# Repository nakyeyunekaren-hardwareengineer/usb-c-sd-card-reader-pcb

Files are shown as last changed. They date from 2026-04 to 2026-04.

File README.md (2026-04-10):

# usb-c-sd-card-reader-pcb
Custom USB-C microSD card reader hardware project featuring schematic design, PCB design and system validation.

# USB-C microSD Card Reader

A custom USB-C microSD card reader PCB designed around the **Genesys Logic GL823K** controller. This project covers the full hardware development flow, from component selection and 
schematic capture to PCB layout, PCB fabrication and assembly ordering, hardware bring-up, hardware debugging and successful memory card read validation.

## Overview

The goal of this project was to design and build a compact USB-C memory card reader that interfaces with a microSD card and communicates with a host device over USB.

This project was completed as a practical electronics and PCB design exercise, with a strong focus on:
- component selection
- schematic design
- PCB layout
- design for manufacture and assembly
- PCB fabrication and assembly ordering
- hardware bring-up
- power rail verification
- debugging and validation

## Key Design Approach

Before starting the design, I selected components carefully to make assembly easier and faster through **JLCPCB**. 
I made sure the parts I chose were available in **JLCPCB Basic** or **Extended** libraries so that the board could be manufactured and assembled with minimal friction.

It was important in designing not just for functionality, but also for **manufacturability** and **assembly convenience**.

## Main Components

The design used the following key parts:

- **GL823K-HCY04** — USB 2.0 flash card reader controller
- **TYPE-C 16PIN 2MD(073)** — USB-C connector
- **Molex 503398-1892** — microSD card connector
- **PRTR5V0U2X / PRTR5V0U2X,215** — USB ESD protection device
- supporting capacitors, resistors and power components for decoupling, pull-downs and signal support

## 3D image


## Printed board


## Features

- USB-C interface
- microSD card support
- GL823K-based controller
- Custom PCB design
- ESD protection
- Manufactured and assembled through JLCPCB
- Working prototype validated through hardware testing

## Tools Used

- **Altium Designer** for schematic capture and PCB layout
- **JLCPCB** for PCB fabrication and PCB assembly
- lab test equipment for bring-up and debugging
- USB host (Laptop) for functional testing

## Manufacturing and Assembly

Fabrication and assembly was done by JLPCB:
- **PCB fabrication**
- **PCB assembly (PCBA)**

This included selecting assembly-friendly parts, preparing manufacturing outputs, and understanding how to structure a design so it can move efficiently into production.

## Bring-Up and Debugging

During initial testing, from the GL823K:
-5v from usb works 
-3.3v from port 9 works 
-3.3v from port 13, 8 doesnt works

This prevented the board from functioning correctly at first. 

A structured debug process was used:
1. Verify USB input power
2. Check GL823K supply-related pins
3. Confirm which rails were active and which were missing
4. Isolate the failing rail
5. Inject external 3.3 V into the affected rail as a debug step

This confirmed the root cause. Once external 3.3 V was injected into the problematic rail, the board was able to function correctly and the memory card could be read successfully.

## Challenges Faced

One practical issue encountered was with the **orientation of the microSD card connector**. The insertion direction was misplaced, which made inserting the card difficult and inconvenient during testing.

Although the board was made to work, this was an important design lesson:
- connector orientation matters just as much as electrical correctness
- usability should be considered during PCB design, not only circuit functionality
- physical interaction with the product is part of good hardware design

Also, a better chip than the GL823K should have been selected. The data sheet was scanty and there was a serious lack of application notes. As a result, 
a 3.3V source was not added to the board because it was assumened that no LDO was needed to change 5V to 3.3V. External injection of 3.3V was done to make the board work.

## Final Result

The project achieved a **working hardware prototype**.

### Outcome
- Board was successfully fabricated and assembled
- USB power-up was verified
- Hardware debugging identified the failing rail
- Memory card reader functionality was demonstrated
- The memory card was successfully read

## What I Learned

Through this project, I gained hands-on experience in:
- selecting components for both function and manufacturability
- designing a custom USB peripheral PCB
- preparing a board for **JLCPCB fabrication and assembly**
- choosing parts available in **JLCPCB Basic and Extended** libraries
- debugging mixed power and interface issues
- verifying PCB functionality through electrical measurements
- identifying board-level faults through structured troubleshooting
- appreciating the importance of connector placement and insertion orientation in real hardware products

## Future Improvements

For the next revision, I would focus on:
- improving the implementation of the affected supply rail
- reviewing critical pin connectivity and local decoupling
- improving connector orientation and mechanical usability
- adding clearer bring-up test points
- documenting test results with photos and measurements

## Project Status

**Prototype completed and functional.**

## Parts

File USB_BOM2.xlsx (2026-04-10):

Comment | Designator | Quantity | Manufacturer | Footprint
CC0805KFX7R7BB105 | C1, C5 | 2 | Yageo Group | FP-CC0805-0_85-MFG
CAP 100nF 16V 0805(2012) | C2, C3, C4, C6 | 4 | KEMET | CAPC0805(2012)145_M
HSMC-C280 | D1 | 1 | Broadcom | FP-HSMC-C280-MFG
USB Type C connector | J1 | 1 |  | CONN16_C16PIN_SHN
microSD Memory Card | J2 | 1 |  | 5033981892
RN73R2ATTD5101A05 | R1, R4 | 2 | KOA Speer | FP-RN73R2A-IPC_C
RT0805FRD0722RL | R2, R3 | 2 | Yageo Group | FP-RT0805-MFG
CRGP0805F10K | R5, R6, R7, R8, R9 | 5 | TE Connectivity | FP-CRGP0805-IPC_C
RN73R2ATTD1001B10 | R10 | 1 | KOA Speer | FP-RN73R2A-IPC_A
GL823K | U1 | 1 |  | SOP64P600X175-16N
ESD protection diode | U2 | 1 |  | SOT190P230X110-4N

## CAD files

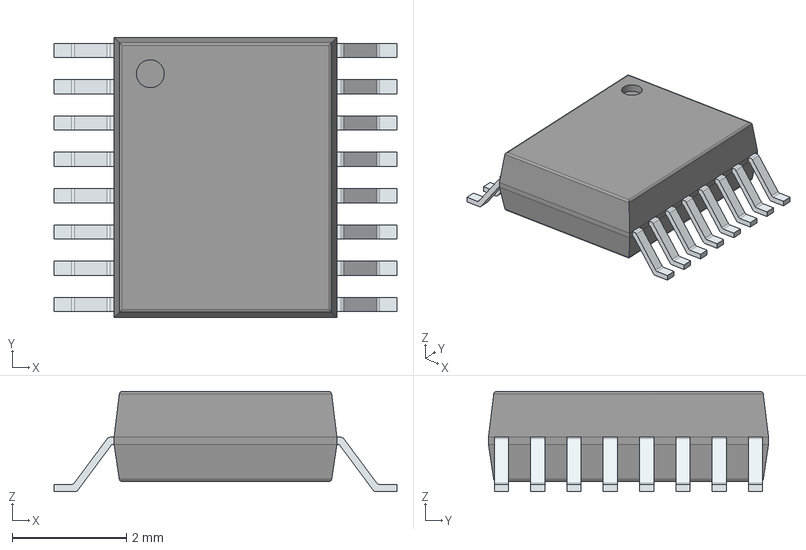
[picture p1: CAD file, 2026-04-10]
3d/GL823K.stp
6.00 x 4.90 x 1.75 mm
PinsArrayLR

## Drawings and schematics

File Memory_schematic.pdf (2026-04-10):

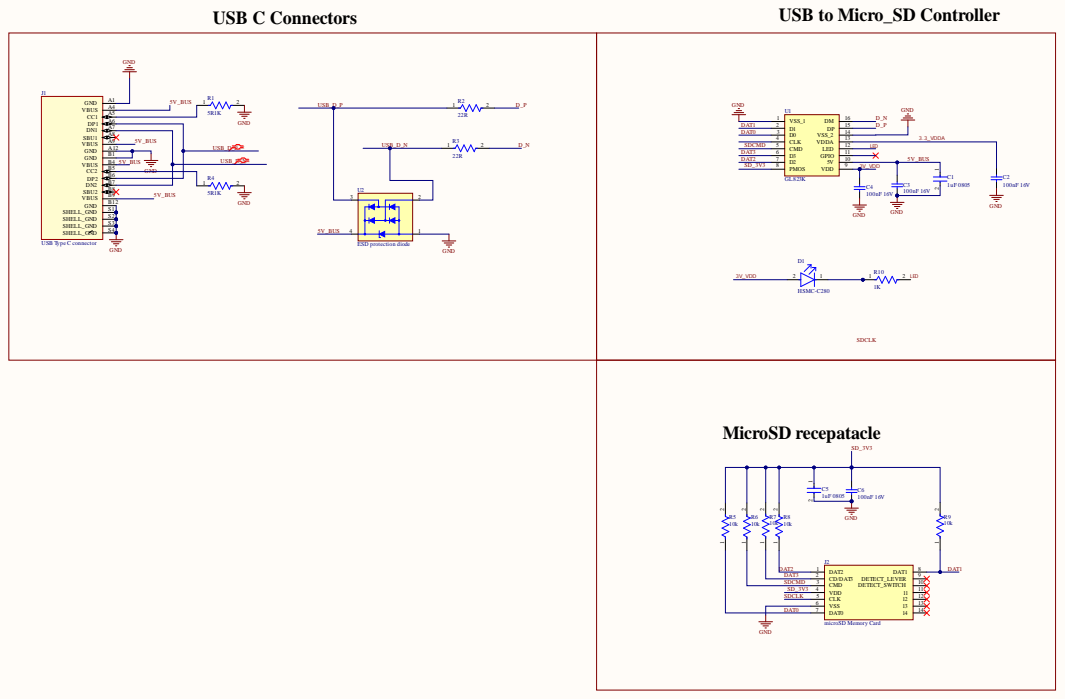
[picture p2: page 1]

D AT2 DAT
3 SDCMD | 2 3
